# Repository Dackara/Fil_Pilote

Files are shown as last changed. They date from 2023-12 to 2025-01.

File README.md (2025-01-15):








# Fil_Pilote
> [!IMPORTANT]
> Carte de **Gestion Centralisé** des `Fil Pilote` de chauffage.
> 
> Design conçus pour être [monté](../main/Image/Exemple/PVBRAIN2_and_Fil_Pilote.png) sur la carte  développé par  et  de la chaine .

> [!NOTE]
> La carte `Fil Pilote` est néanmoins totalement utilisable sans la carte  (le hardware fonctionne avec n'importe quel ESP32 / ESP8266, ou tout autre système compatible **i2c**).
>
> L'intérêt est que les trous de fixation des deux carte correspondent. Cela permet de les imbriquer l'une sur l'autre, tout en profitant de l'[esp32](https://amzn.to/3RCapBQ) déjà présent sur le PvBrain.
> 
> Montage sur le  également [possible](../main/Image/Exemple/PVBRAIN1_and_Fil_Pilote.png).

> [!TIP]
> Développé pour .
> 
> Automatisable sous  très simplement en suivant par exemple ce tuto sur .

## Ce que permet la carte :
### Contrôler jusqu'à 4 zones de chauffage par carte :
 > - Une seule carte permet de contrôler jusqu'à 4 zones de chauffage en 6 ordres (plusieurs chauffages peuvent être câblés dans une même "zone").
 > - Possibilité d'utiliser plusieurs cartes, de jumeler deux cartes ensemble en n'utilisant qu'un seul i2c extender [SX1509](https://amzn.to/3vddUae) (via un système de pontage) et un seul [esp32](https://amzn.to/3RCapBQ).
 > - Deux entrées de phase sont disponible par carte pour permettre le montage en Triphasé.
 > - Son design permet de réduire le coût de fabrication des PCB pour ceux qui souhaitent utiliser plus de 4 zones ou l'utiliser en Triphasé.
### Utilisation en Monophasé ou Triphasé :
 > - En Monophasé : Une seule phase par carte, dans ce cas, faire le pontage sur **PH2** comme indiqué au verso de la carte.
 > - En Triphasé : deux phases par carte, jumelage de deux cartes pour obtenir `3x2` ou `2x2 + 1x4`. (Le signal **230V** envoyé au `Fil Pilote` doit provenir de la même `Phase` que l'alimentation du chauffage piloté !)
 > - Possible aussi pour des montages moins courant d'avoir une phase sur `réseau ENEDIS-EDF` et une phase sur `système Solaire`.
### En option :
 > - Un module **`TIC`** { **T**<sub>_élé_</sub> **I**<sub>_nformation_</sub> **C**<sub>_lient_</sub> } pour communiquer avec les **Compteurs Linky** est disponble.

## Le code ESPHome :
Le code est simplifié pour la modification via `packages:` et `substitutions:`. 

Tout se passe dans le fichier [fil_pilote.yaml](../main/Software_esphome/fil_pilote.yaml) présent à la racine.

L'intégralité des fichiers présents dans [ce répertoire](../main/Software_esphome) sont nécessaire à son bon fonctionnement.

## La carte :
- Fichier **Gerber** et **BOM** : [Dossier Hardware](../main/Hardware)

| Face avant | Face arrière |
| :---: | :---: |
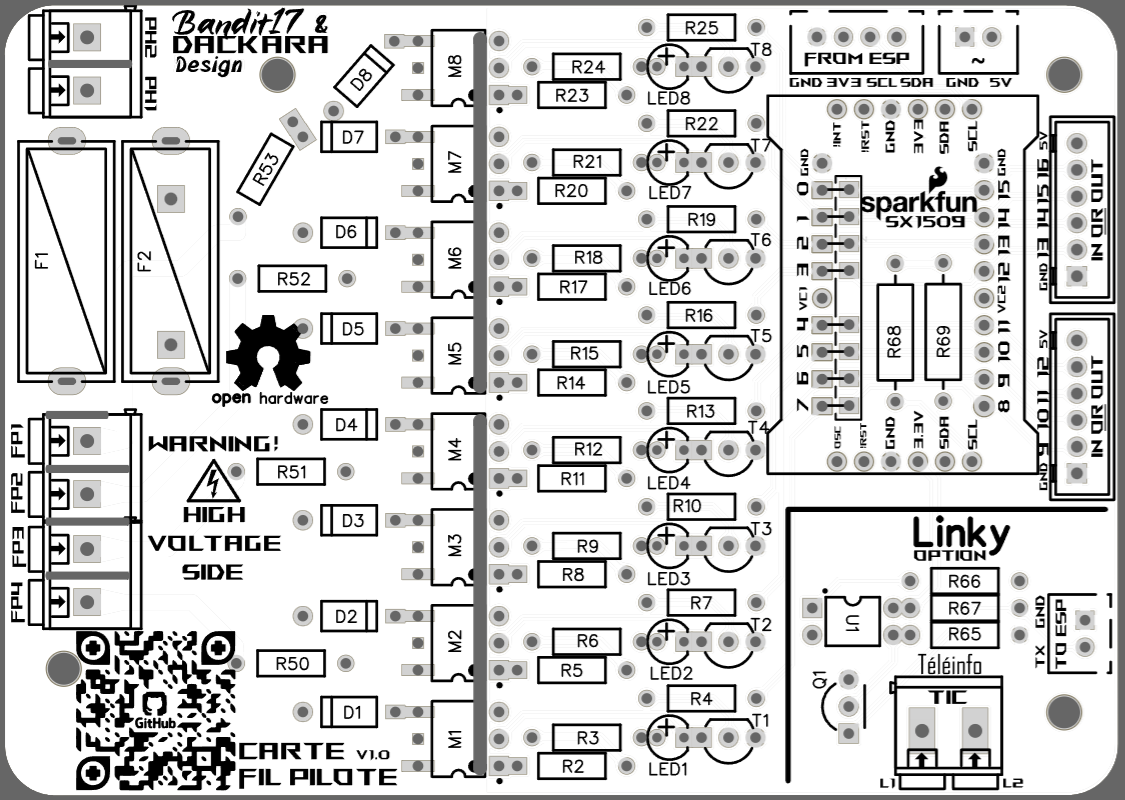
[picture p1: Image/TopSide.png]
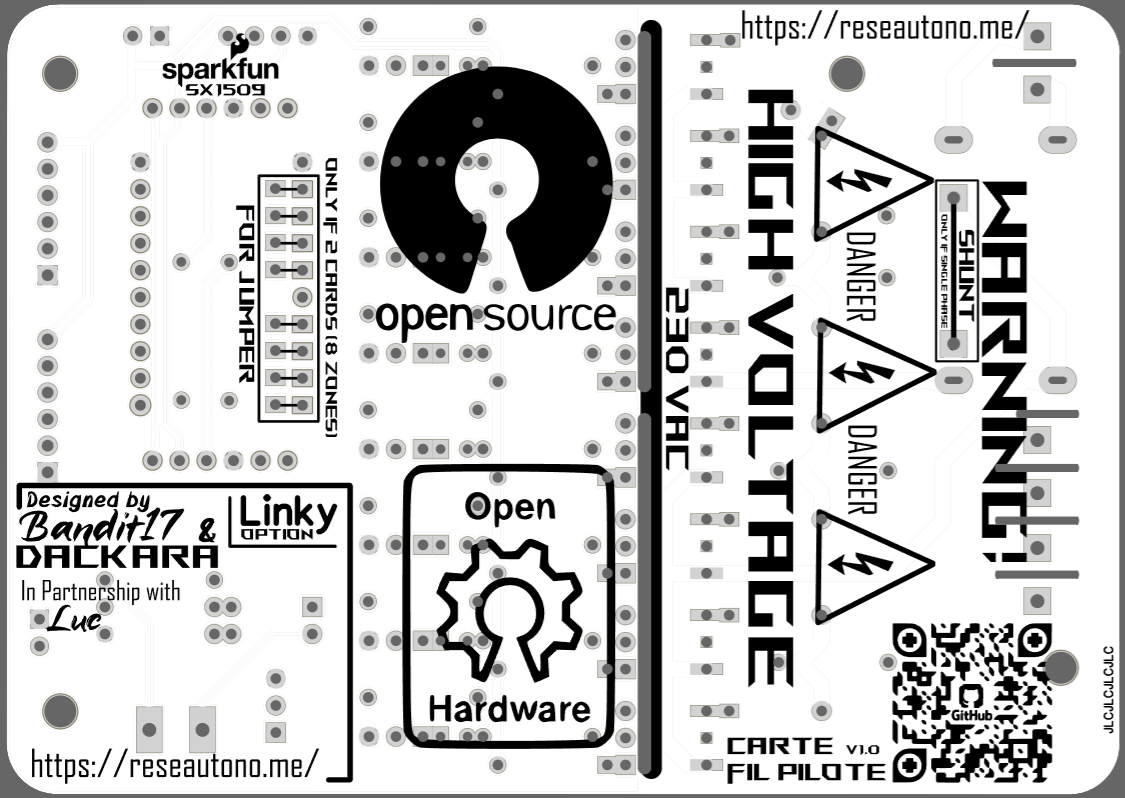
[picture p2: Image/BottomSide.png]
|  |  |
| __Vue 3D__ | __Circuit__ |
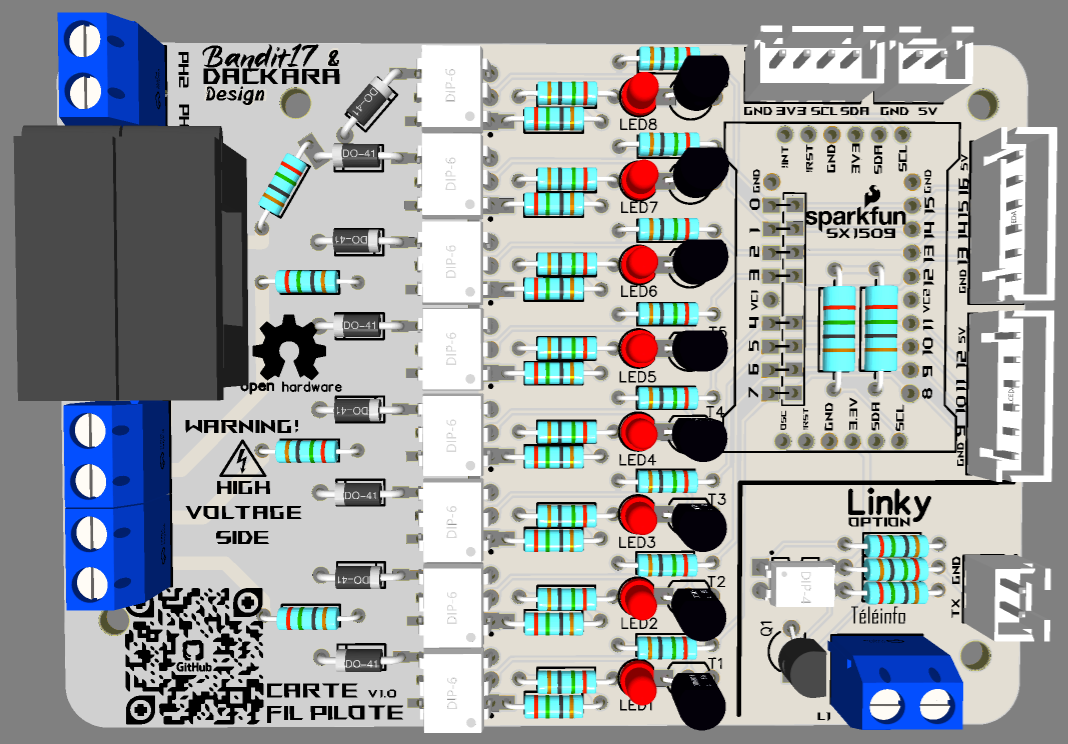
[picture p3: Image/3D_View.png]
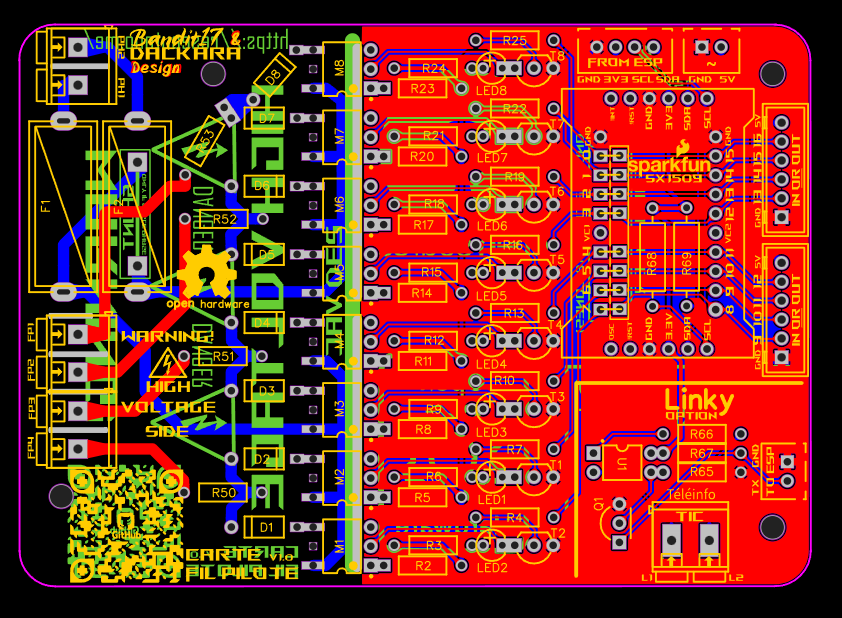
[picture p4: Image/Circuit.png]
|  |  |
| __Schematic Fil Pilote__  | __Schematic TIC__ |
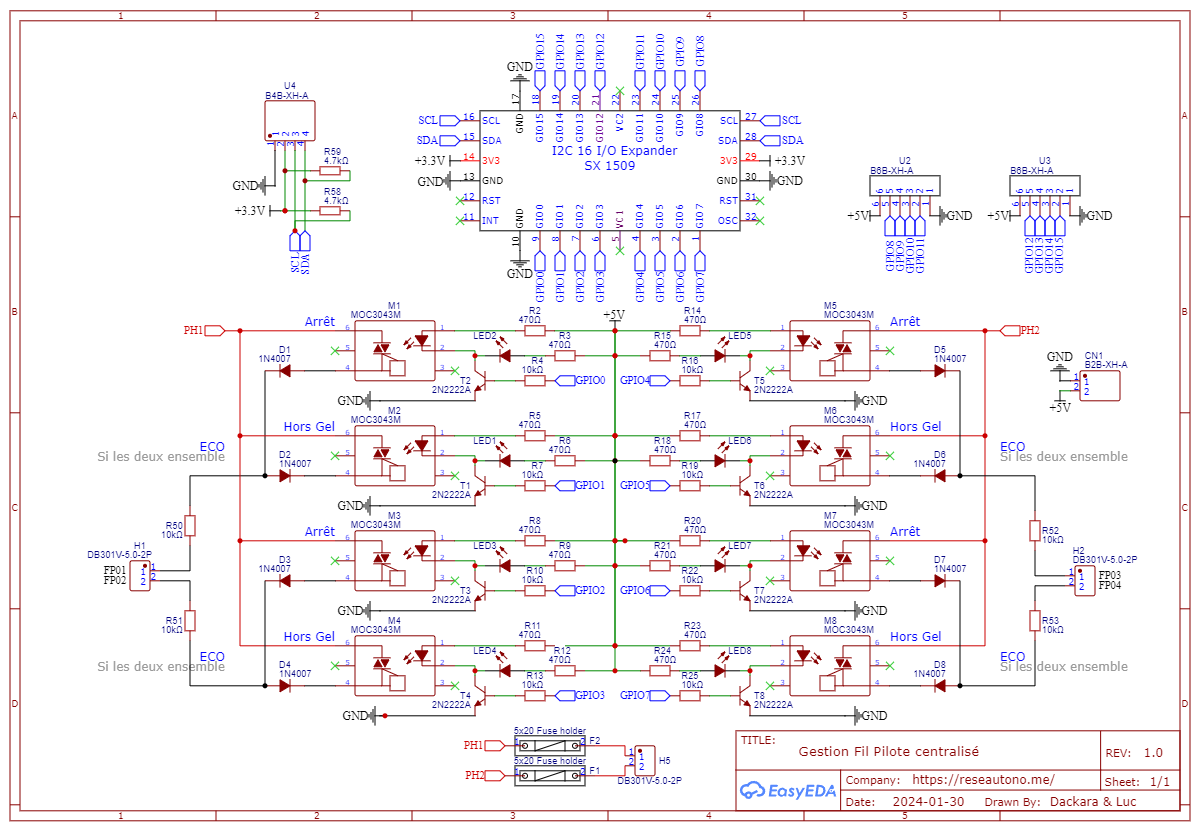
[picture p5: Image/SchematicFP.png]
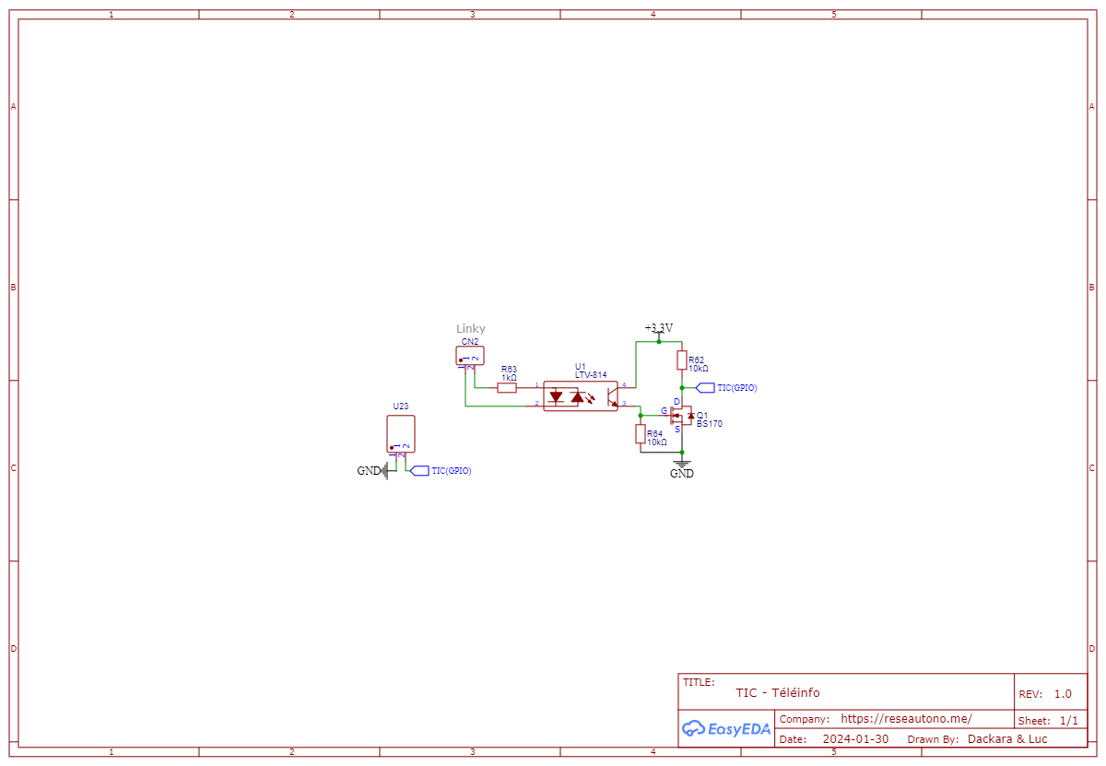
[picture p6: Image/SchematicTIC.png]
|  |  |

### Fonctionnement du Fil Pilote :
- Principe de fonctionnement en [image](../main/Image/Exemple/Signal_fil_pilote.png).
- Démonstration du fonctionnement des 6 ordres en [image](../main/Image/Exemple/Fil_pilote_demo.png).

### Crédit :
- Schéma électronique :  & 
- Designe PCB :  & 
- Code esphome : 

## Impression 3D :
[Fichier 3D](../main/Hardware/3D_Print) à imprimer pour montage de la carte sur rail DIN (tableau électrique).
| Face avant | Face arrière |
| :---: | :---: |
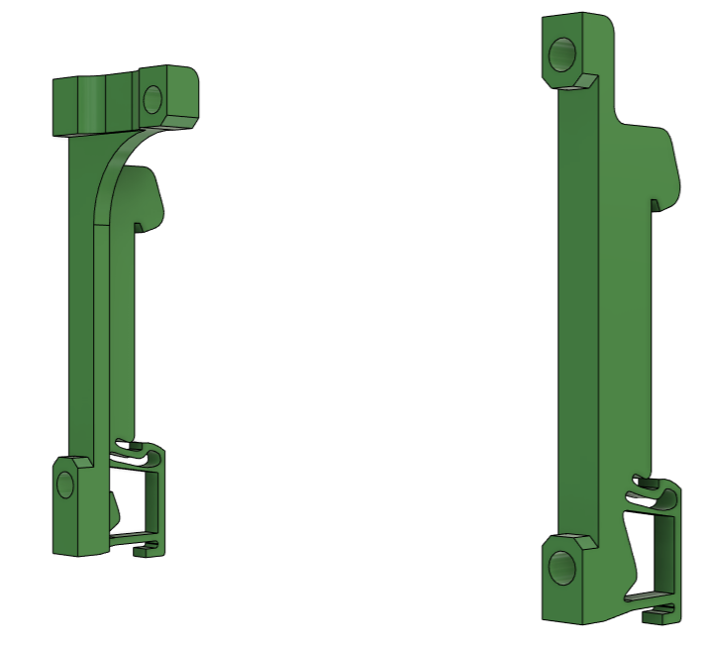
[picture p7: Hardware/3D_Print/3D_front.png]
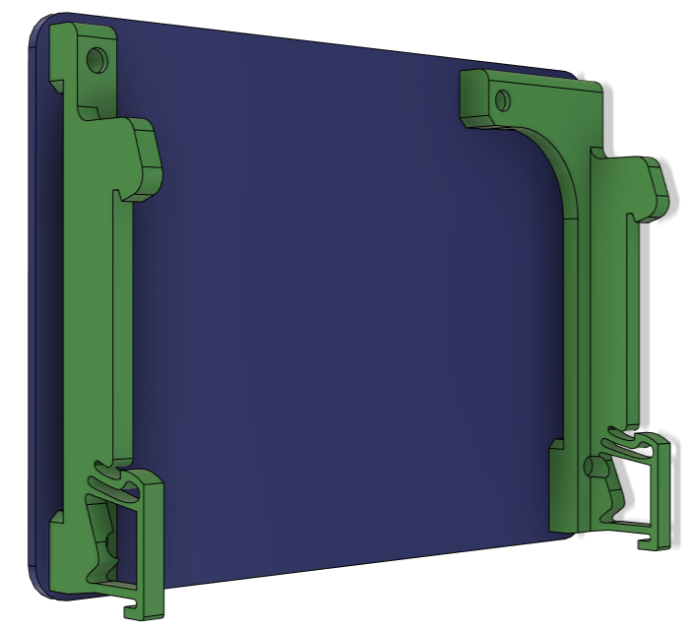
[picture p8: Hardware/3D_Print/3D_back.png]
|  |  |

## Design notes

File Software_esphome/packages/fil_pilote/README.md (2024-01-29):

## Le Fil Pilote, qu'est-ce que c'est ? A quoi ça sert ?
Le "Fil Pilote" est un système Français inventé dans les années 80/90 pour piloter de façon centralisée et par plages horaires, les thermostats des systèmes de chauffage.

A la suite d'une concertation entre les grandes marques françaises d'appareils de chauffage, cette technologie est devenue un "standard de marché" pour les logements neufs construits à partir de 1995.

À l’aube des années 2000, la norme RT2000, rend sa présence obligatoire (par la réception de 4 ordres de contrôle) dans les logements neuf.

Peut de temps après, le protocole d'origine à 4 ordres évoluera pour un contrôle à 6 ordres, les deux dernier n'étant eux, pas obligatoire.

Le Fil Pilote permet ainsi, d'adapter au mieux, la production de chaleur, au moment d'occupation du logement. Une économie d'énergie d'environ 20% étant alors généralement constaté.

## Mais alors ? Comment ça fonctionne ?
Le principe est simple : Par un fil dédié à cet usage, les radiateurs électriques, reçoivent sous forme de signaux électriques de faible intensité, des ordres simples pour contrôler leur état.

La régulation et la mesure de température reste cependant toujours réalisée par le thermostat de chaque appareil. 
- Fil pilote 4 ordres : Confort, éco, hors gel, arrêt
- Fil pilote 6 ordres (protocole défini par le GIFAM) : Confort, confort -1°C, confort -2°C, éco, hors gel, arrêt

> [!NOTE]
> ### La norme "Fil Pilote" :
> - Les ordres sont générés et pris en compte par rapport au neutre
> - Signaux électriques (tension efficace) : 230 volts, +115 volts, -115 volts / 0,1 Ampère max
> - Le standard GIFAM encadre l'impédance d'entrée des récepteurs entre 100k et 500 kilo ohms, ce qui permet de relier de nombreux appareils de chauffage sur la même ligne. Souvent de 10 à 20 selon les caractéristiques du matériel émetteur. Par exemple, un programmateur pouvant délivrer 30 mA peut commander environ 15 thermostats d'impédance 200 K ohms.
> - Les signaux "confort -1°C" et "confort -2°C" correspondent à des périodes de présence du 230 volts alternatifs de 3 et 7 secondes espacées de périodes d'absence de signal d'environ 5 minutes. Pour des raisons techniques, la prise en compte de ces ordres peut demander un délai de 5 minutes. Quand un récepteur 4 ordres reçoit ces ordres spéciaux, il les ignore et reste en mode confort.
>
>   - __Confort :__ température de consigne en usage normal réglable de 7 à 30 °C par l'utilisateur
>   - __Eco ou réduit :__ température de confort abaissée de 3,5°C
>   - __Hors gel :__ régulation réglée sur 7 à 8°C
>   - __Arrêt :__ mise à l'arrêt de l'appareil (ou délestage)

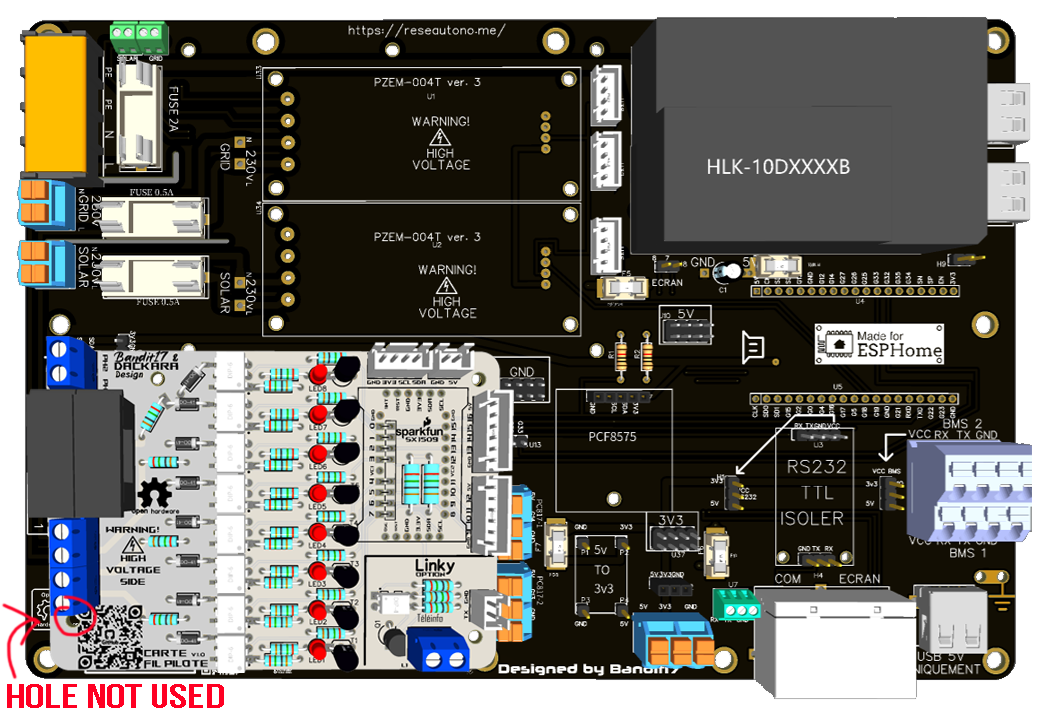
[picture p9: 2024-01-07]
Image/Exemple/PVBRAIN1_and_Fil_Pilote.png

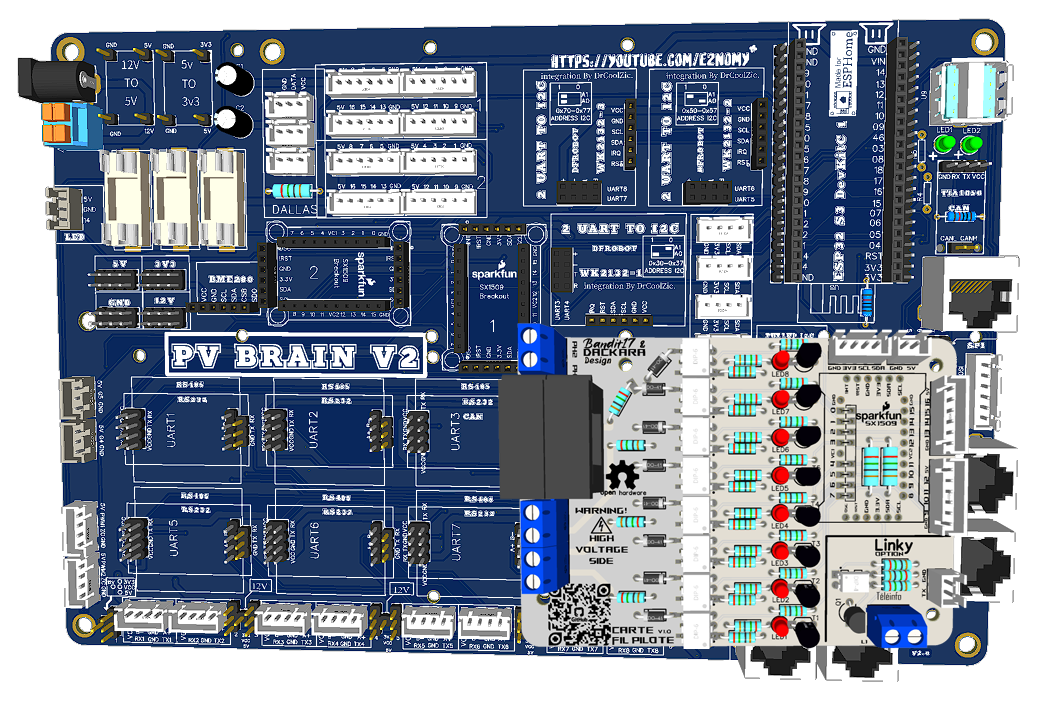
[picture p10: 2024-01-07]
Image/Exemple/PVBRAIN2_and_Fil_Pilote.png

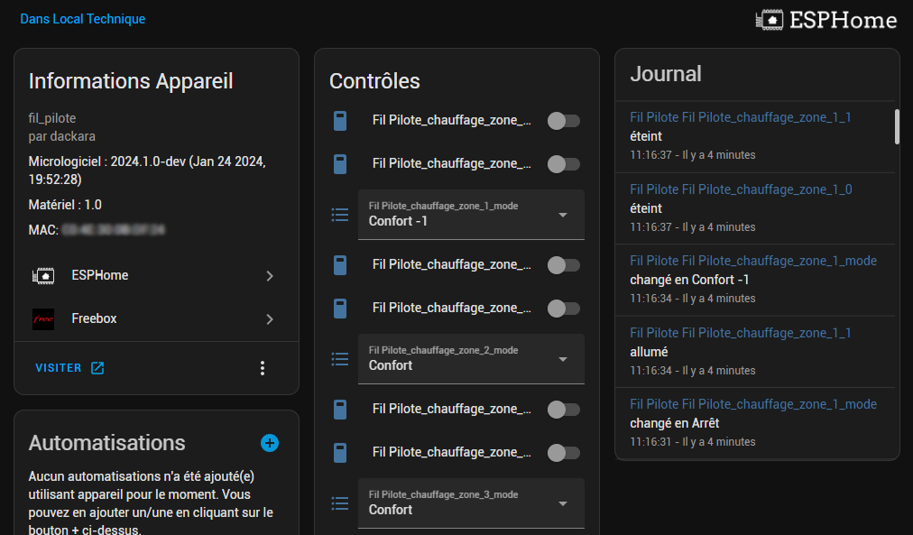
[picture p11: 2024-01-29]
Image/Exemple/HomeAssistantAPI.png

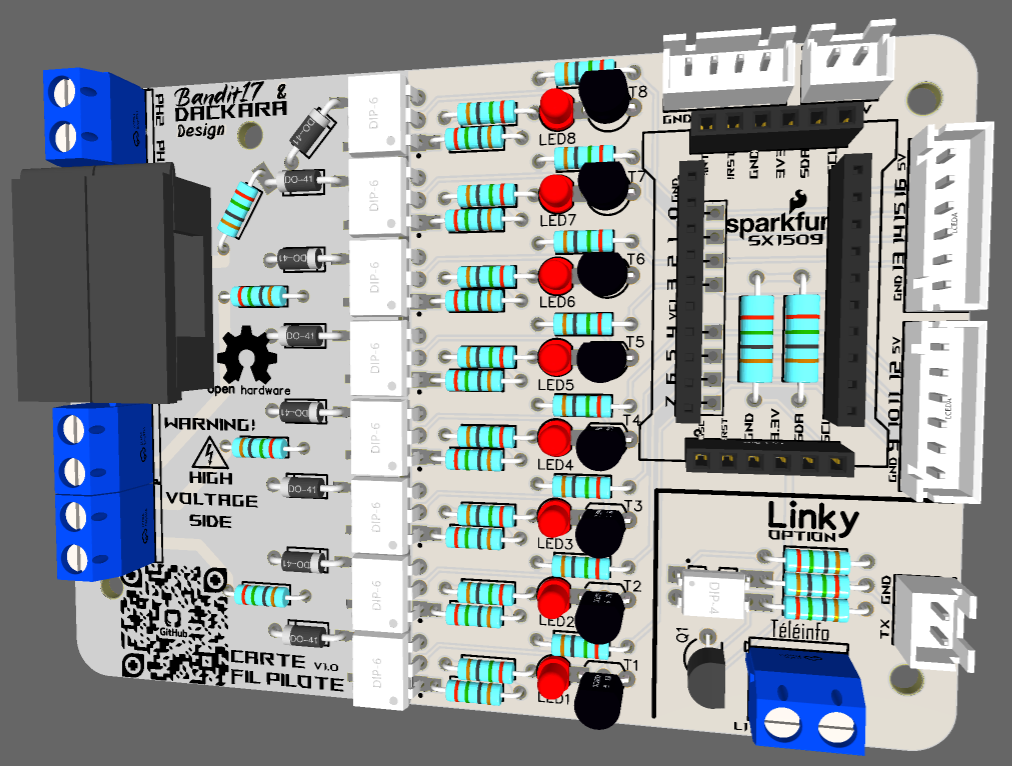
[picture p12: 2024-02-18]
Image/Exemple/Fil_Pilote_3D_Base.png

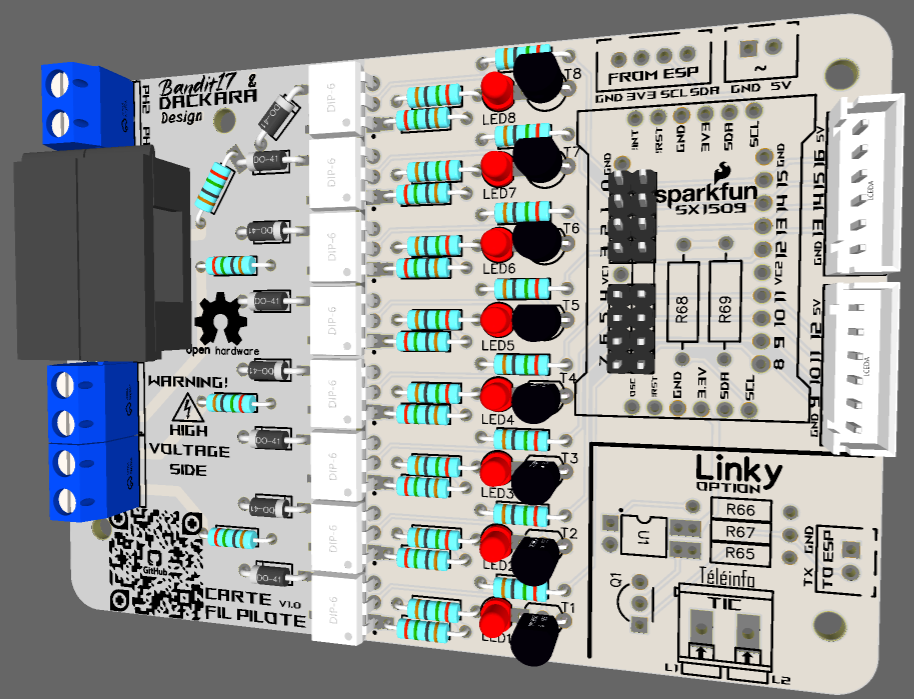
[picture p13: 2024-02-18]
Image/Exemple/Fil_Pilote_3D_Slave_NoLinky.png

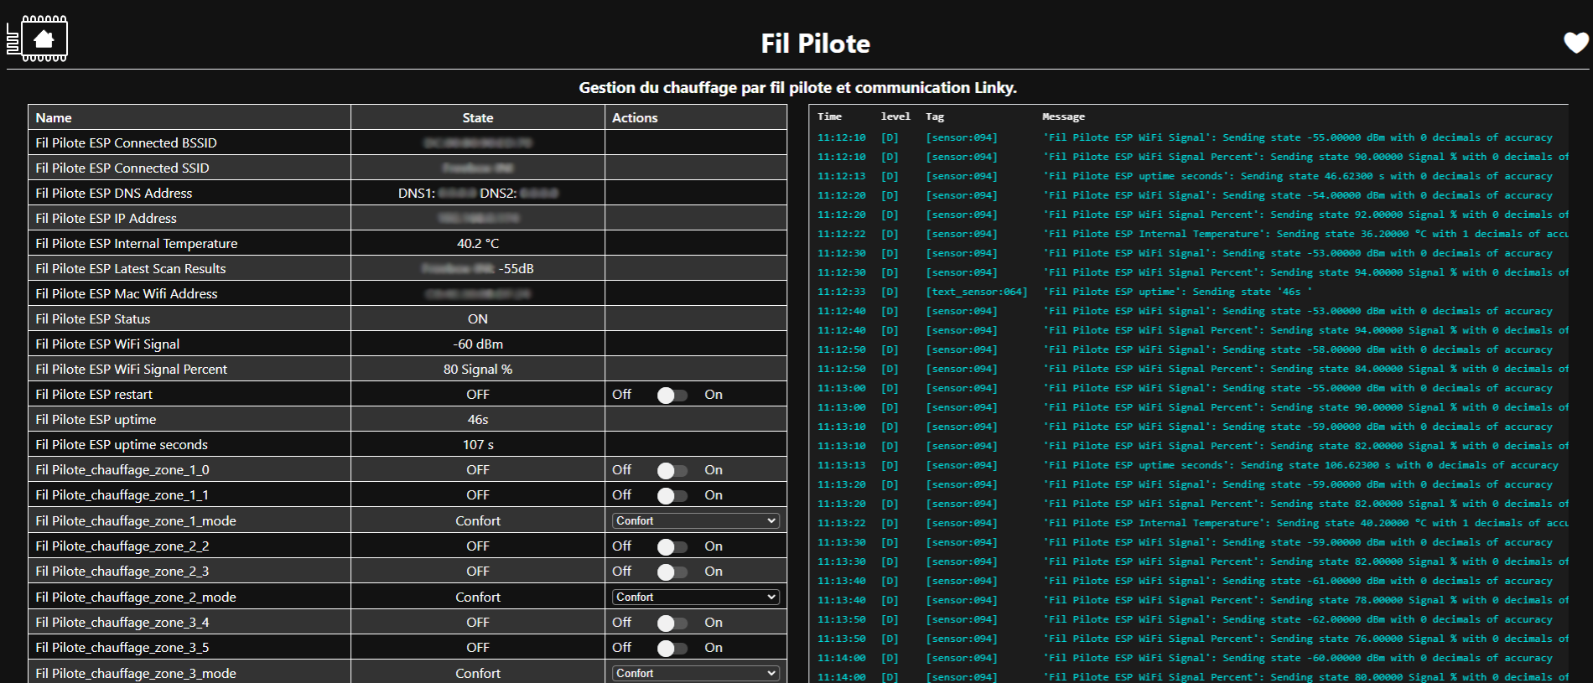
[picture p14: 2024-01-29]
Image/Exemple/WebServer.png

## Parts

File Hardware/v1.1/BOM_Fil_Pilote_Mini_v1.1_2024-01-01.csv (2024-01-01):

Name | Designator | Quantity | LCSC Part | Lien Amazon | Lien Aliexpress | Note
MOC3043M | M8,M1,M2,M3,M4,M5,M6,M7 | 8 | C6171202 | https://amzn.to/3NEjiK0 | https://s.click.aliexpress.com/e/_DlNmgaz
SX1509 | SX1509 | 1 |  | https://amzn.to/3RsjCN2 | https://s.click.aliexpress.com/e/_DlgzyUt
4.7kΩ | R68,R69 | 2 | C385631 | https://amzn.to/3GTGnEz | https://s.click.aliexpress.com/e/_Dciup05 | 1/4W
CONN-TH_B2B-XH-A-LF-SN | U22 | 1 | C158012 | https://amzn.to/3TBzzmA | https://s.click.aliexpress.com/e/_DkmSizL | Connecteur 2pin
CONN-TH_6P-P2.50_B6B-XH-A-LF-SN | U10,U11 | 2 | C144397 | https://amzn.to/3TBzzmA | https://s.click.aliexpress.com/e/_DkmSizL | Connecteur 6pin
10kΩ | R4,R7,R10,R13,R16,R19,R22,R25 | 8 | C410695 | https://amzn.to/3GTGnEz | https://s.click.aliexpress.com/e/_Dciup05 | 1/4W
DB301V-5.0-2P | TIC,H1,H2,H5 | 3 | C395882 | https://amzn.to/41xVoWk | https://s.click.aliexpress.com/e/_DcG4sTR | Bornier 2pin
B4B-XH-A(LF)(SN) | JST1 | 1 | C144395 | https://amzn.to/3TBzzmA | https://s.click.aliexpress.com/e/_DkmSizL | Connecteur 4pin
1N4007 | D1,D2,D3,D4,D5,D6,D7,D8 | 8 | C2978779 | https://amzn.to/3RyhLXa | https://s.click.aliexpress.com/e/_DelQiRf
5x20 Fuse holder | F1,F2 | 2 | C3131 | https://amzn.to/3O2c8Q7 | https://s.click.aliexpress.com/e/_Dk60DEZ | 1 seul si une seul phase
204-10SDRD/S530-A3-L | LED2,LED1,LED3,LED4,LED5,LED6,LED7,LED8 | 8 | C84774 | https://amzn.to/48c4Tgk | https://s.click.aliexpress.com/e/_DeG37NR
470Ω | R2,R3,R5,R6,R8,R9,R11,R12,R14,R15,R17,R18,R20,R21,R23,R24 | 16 | C410615 | https://amzn.to/3GTGnEz | https://s.click.aliexpress.com/e/_Dciup05 | 1/4W
10kΩ | R50,R51,R52,R53 | 4 | C433797 | https://amzn.to/3GRP8iG | https://s.click.aliexpress.com/e/_DDZ9Je1 | 1W
2N2222A | T2,T1,T3,T4,T5,T6,T7,T8 | 8 | C5330385 | https://amzn.to/3v42aXx | https://s.click.aliexpress.com/e/_DkvNLqh
## Option Linky | ################### | #### | #### | ################### | ################### | ###################
LTV-814 | U1 | 1 | C10790 | https://amzn.to/3vg71oU
CONN-TH_B2B-XH-A-LF-SN | U23 | 1 | C158012 | https://amzn.to/3TBzzmA | https://s.click.aliexpress.com/e/_DkmSizL | Connecteur 2pin
BS170 | Q1 | 1 | C111691 | https://amzn.to/3ve7A2r | https://s.click.aliexpress.com/e/_DnDtepL
10kΩ | R65,R67 | 2 | C410695 | https://amzn.to/3GTGnEz | https://s.click.aliexpress.com/e/_Dciup05 | 1/4W
1kΩ | R66 | 1 | C433798 | https://amzn.to/3GTGnEz | https://s.click.aliexpress.com/e/_Dciup05 | 1/4W
XY118-5.0-2P | CN4 | 1 | C784922 | https://amzn.to/41xVoWk | https://s.click.aliexpress.com/e/_DcG4sTR | Bornier 2pin
## Complément | ################### | #### | #### | ################### | ################### | ###################
Fusible verre |  | 2 |  | https://amzn.to/3TExkPw | https://s.click.aliexpress.com/e/_Dk60DEZ | 1 seul si une seul phase
Pin Header |  | ~ |  | https://amzn.to/3TwQVkJ | https://s.click.aliexpress.com/e/_DcQ7kJf
## Optionnel | ################### | #### | #### | ################### | ################### | ###################
Vis nylon M3 |  |  |  | https://amzn.to/3NFw8b3 | https://s.click.aliexpress.com/e/_Dkr2PhP | Pour fixation sur le PvBrain ou autre
Esp32 |  |  |  | https://amzn.to/3RCapBQ | https://s.click.aliexpress.com/e/_DBJfCql

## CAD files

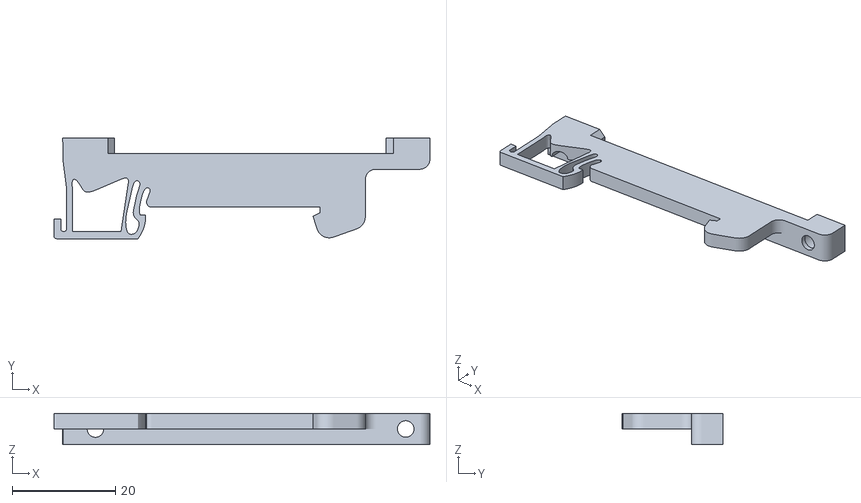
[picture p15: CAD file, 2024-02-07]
Hardware/3D_Print/PVbrain_addon_card_Support_Right_v1.0.stl
72.7 x 19.4 x 6.00

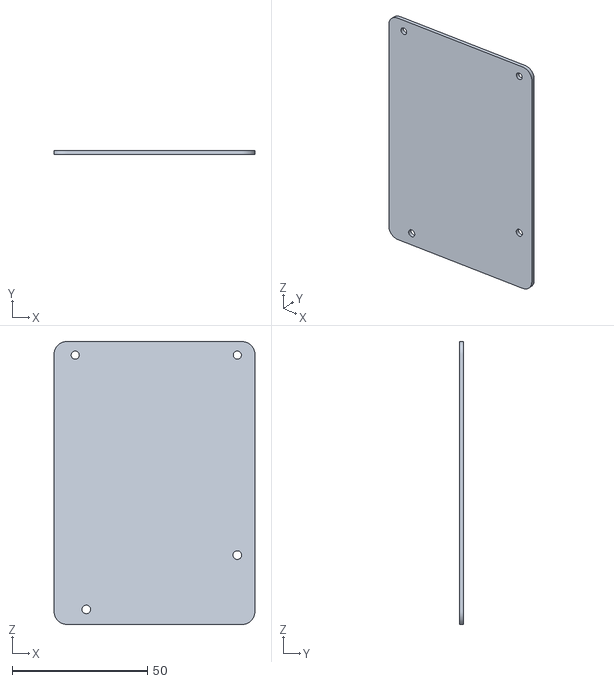
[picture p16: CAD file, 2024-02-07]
Hardware/3D_Print/PVbrain_addon_card_Plastic_v1.0.stl
74.3 x 1.60 x 104.7

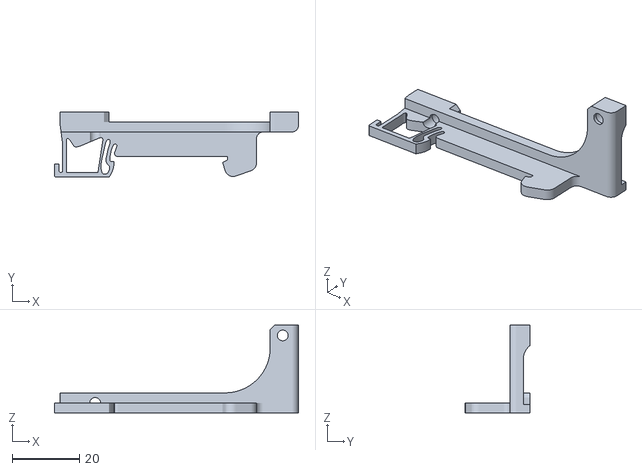
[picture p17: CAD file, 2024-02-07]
Hardware/3D_Print/PVbrain_addon_card_Support_Left_v1.0.stl
72.7 x 19.4 x 26.2

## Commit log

2023-12-10 Rename PCB_Fil Pilote _Mini_v1_2023-12-10.png to Circuit.png
2024-02-07 Add 3D Print Files
    3D printable Parts.
    [PVbrain_addon_card_Plastic_v1.0.stl, PVbrain_addon_card_Support_Left_v1.0.stl, PVbrain_addon_card_Support_Right_v1.0.stl]
2024-03-03 Update
    add v1.1 gerber files
    [BOM_Fil_Pilote_Mini_v1.1_2024-01-01.csv, BOM_Fil_Pilote_Mini_v1_2024-01-01.csv, PickAndPlace_Fil_Pilote_Mini_v1_2024-01-27.csv]

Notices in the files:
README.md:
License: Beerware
